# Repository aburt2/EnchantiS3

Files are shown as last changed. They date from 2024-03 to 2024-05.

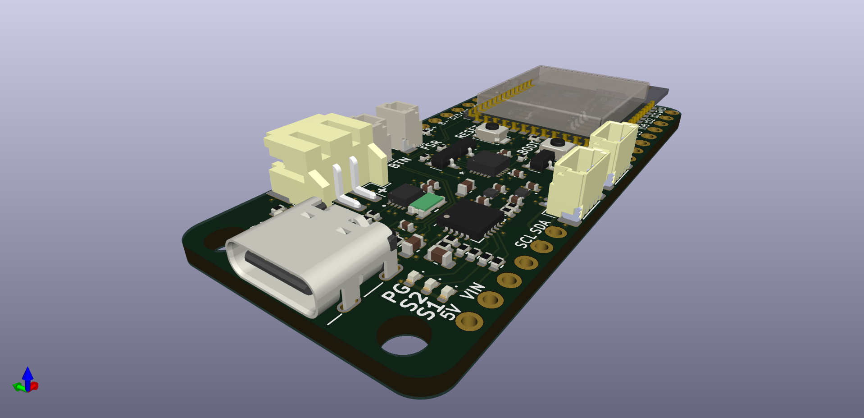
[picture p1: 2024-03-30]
enchantiS3-board/Screenshots/tstick-5gw-pro-USB-V2-pcb-angle.png

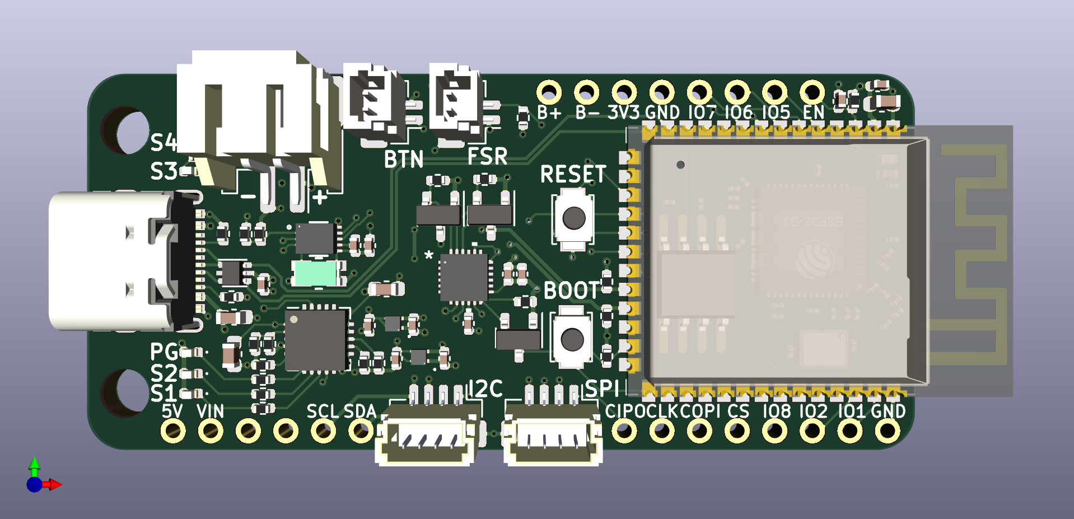
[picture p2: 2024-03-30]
enchantiS3-board/Screenshots/tstick-5gw-pro-USB-V2-pcb-front.png

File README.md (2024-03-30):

# EnchantiS3
 Repository for hardware and firmware for the EnchantiS3 board. The EnchantiS3 is a board based on the ESP32-S3 WROOM 2 module from Espressif. It includes a fuel gauge and inertial measurement unit (IMU). The board can be powered from both the USB-C port or a 3.7V lithium ion battery.

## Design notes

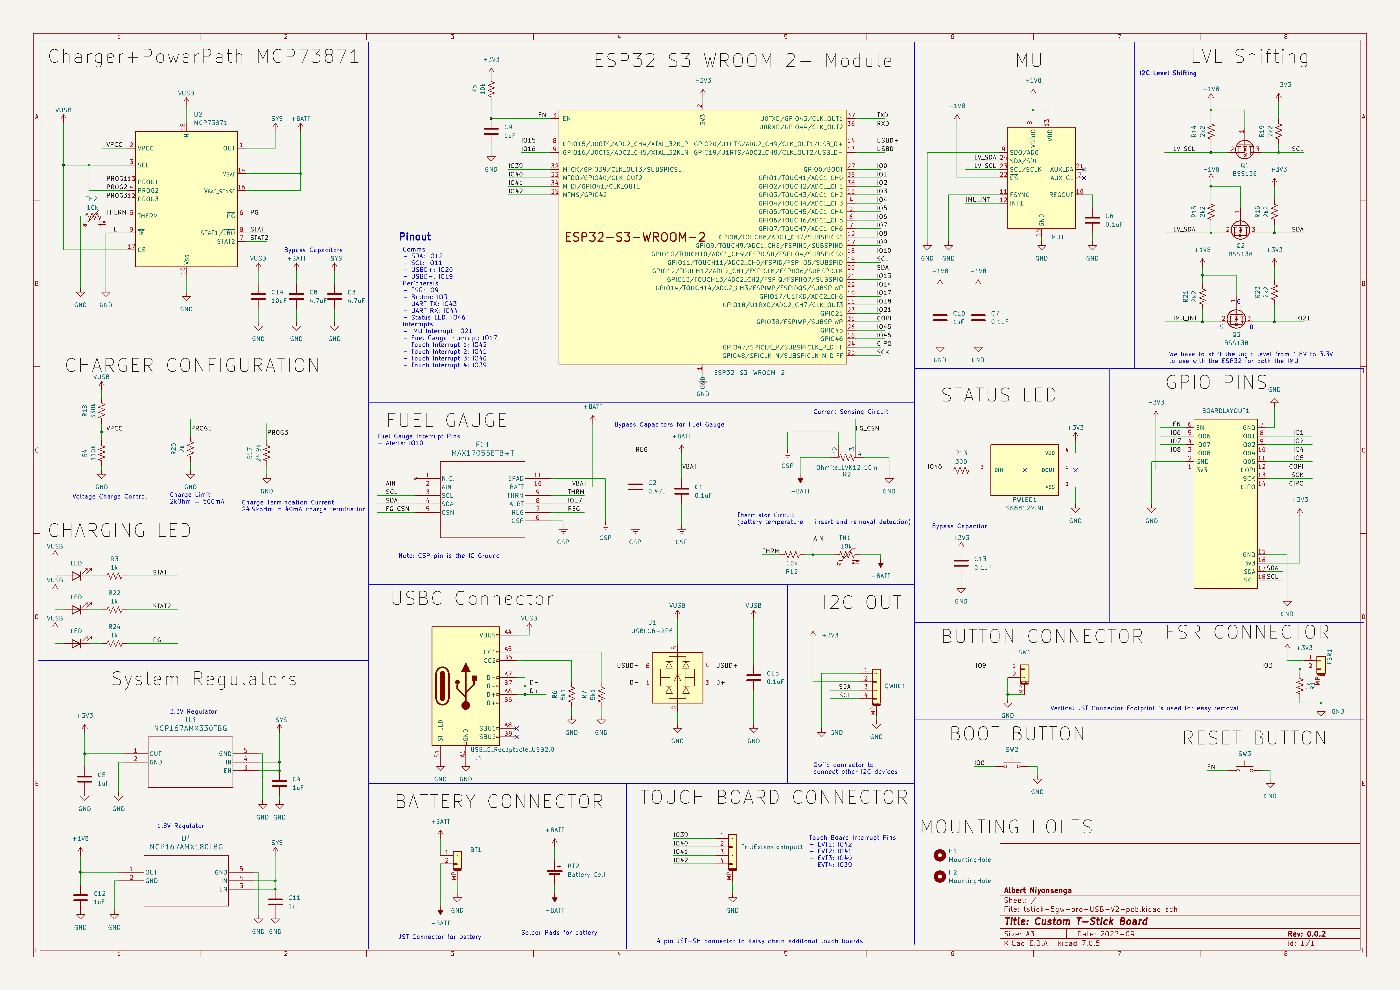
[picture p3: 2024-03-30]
enchantiS3-board/Screenshots/tstick-5GW-schematic.png

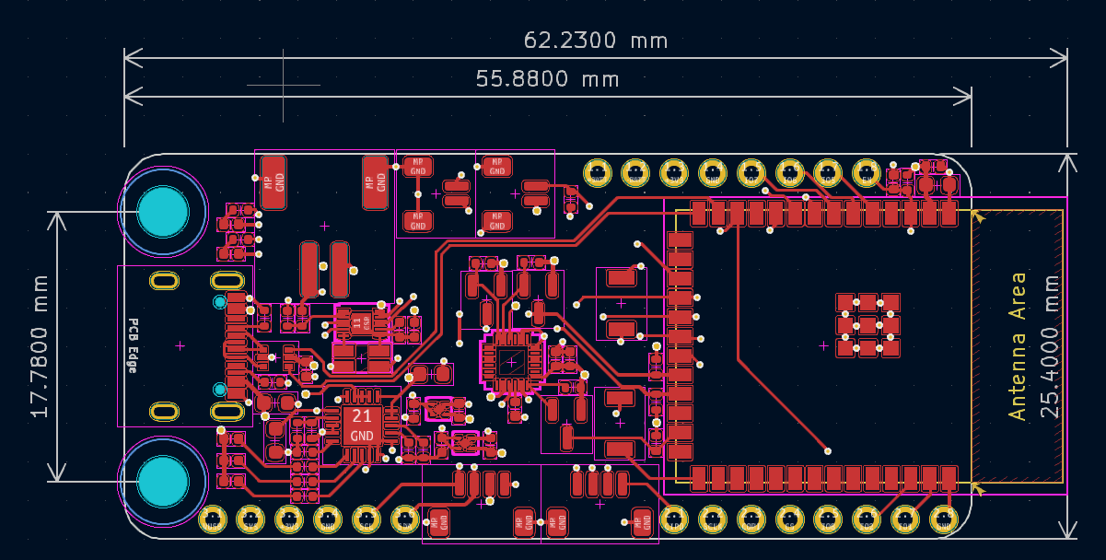
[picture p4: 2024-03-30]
enchantiS3-board/Screenshots/pcb_layout_top_layer.png

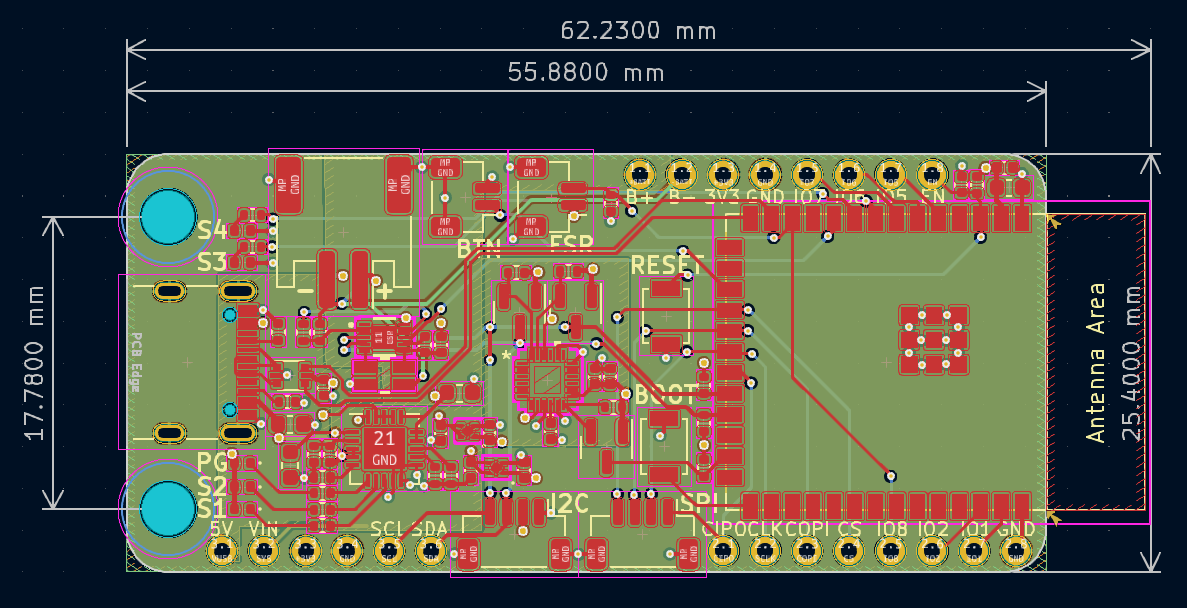
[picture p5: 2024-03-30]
enchantiS3-board/Screenshots/pcb_layout.png

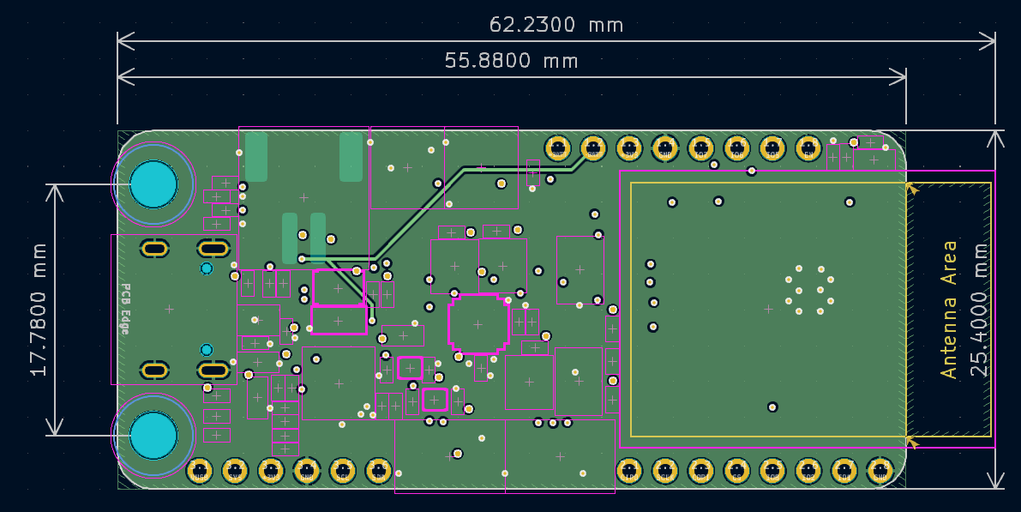
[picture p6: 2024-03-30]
enchantiS3-board/Screenshots/pcb_layout_gnd_layer.png

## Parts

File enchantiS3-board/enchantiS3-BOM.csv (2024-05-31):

Manufacturer | Mfg Part # | Qty | Reference(s) | Description Value Pkg | Note
Analog Devices Inc./Maxim Integrated | MAX17262REWL+T | 1 | U6 | Battery Fuel Gauge IC LiFePO4/Li-ion 9-WLP (1.47x1.45)
ANBON SEMICONDUCTOR (INT'L) LIMITED | BSS138 | 3 | Q1, Q2, Q3 | N-Channel 50 V 220mA (Ta) 350mW (Ta) Surface Mount SOT-23
Espressif Systems | ESP32-S3-WROOM-2-N32R8V | 1 | MCU1 | Bluetooth, WiFi 802.11b/g/n, Bluetooth v5.0 Transceiver Module 2.4GHz PCB Trace Surface Mount | Alternatives: ESP32-S3-WROOM-2-N16R8V
GCT | USB4105-GF-A | 1 | J1 | USB-C (USB TYPE-C) USB 2.0 Receptacle Connector 24 (16+8 Dummy) Position Surface Mount, Right Angle; Through Hole
Inolux | IN-S42BT5B | 1 | STATLED1 | Blue 467nm LED Indication - Discrete 2.9V 0402 (1005 Metric)
Inolux | IN-S42BT5A | 1 | STATLED2 | Amber 605nm LED Indication - Discrete 2V 0402 (1005 Metric)
JST Sales America Inc. | BM02B-SRSS-TB | 2 | ANG1, ANG2 | Connector Header Surface Mount 2 position 0.039" (1.00mm)
JST Sales America Inc. | S2B-PH-SM4-TB | 1 | BT1 | Connector Header Surface Mount, Right Angle 2 position 0.079" (2.00mm)
JST Sales America Inc. | BM04B-SRSS-TB | 2 | TOUCH1, TOUCH2 | Connector Header Surface Mount 4 position 0.039" (1.00mm)
Kingbright | APHHS1005SURCK | 1 | CHARGLED1 | Red 630nm LED Indication - Discrete 1.95V 0402 (1005 Metric)
Kingbright | APHHS1005SYCK | 1 | CHARGLED2 | Yellow 590nm LED Indication - Discrete 2V 0402 (1005 Metric)
Kingbright | APHHS1005CGCK | 1 | CHARGLED3 | Green 570nm LED Indication - Discrete 2.1V 0402 (1005 Metric)
Microchip Technology | MCP73871-2CCI/ML | 1 | U2 | QFN-20 Battery Management ICs ROHS
Murata Electronics | GRT155R61C474KE01D | 1 | C2 | 0.47 µF ±10% 16V Ceramic Capacitor X5R 0402 (1005 Metric)
Omron Electronics Inc-EMC Div | B3U-1000P | 2 | SW1, SW2 | Tactile Switch SPST-NO Top Actuated Surface Mount
onsemi | NCP167AMX330TBG | 2 | U3, U5 | Linear Voltage Regulator IC Positive Fixed 1 Output 700mA 4-XDFN (1x1), 3.3V
onsemi | NCP167AMX180TBG | 1 | U4 | Linear Voltage Regulator IC Positive Fixed 1 Output 700mA 4-XDFN (1x1), 1.8V
Panasonic Electronic Components | ERJ-2RKF1001X | 6 | R1, R3, R8, R10, R22, R24 | 1 kOhms ±1% 0.1W, 1/10W Chip Resistor 0402 (1005 Metric) Automotive AEC-Q200 Thick Film
Panasonic Electronic Components | ERJ-2RKF1103X | 1 | R4 | 110 kOhms ±1% 0.1W, 1/10W Chip Resistor 0402 (1005 Metric) Automotive AEC-Q200 Thick Film
Panasonic Electronic Components | ERJ-2RKF1002X | 2 | R5, R9 | 10 kOhms ±1% 0.1W, 1/10W Chip Resistor 0402 (1005 Metric) Automotive AEC-Q200 Thick Film
Panasonic Electronic Components | ERJ-2RKF5101X | 2 | R6, R7 | 5.1 kOhms ±1% 0.1W, 1/10W Chip Resistor 0402 (1005 Metric) Automotive AEC-Q200 Thick Film
Panasonic Electronic Components | ERJ-2RKF2201X | 6 | R14, R15, R16, R19, R21, R23 | 2.2 kOhms ±1% 0.1W, 1/10W Chip Resistor 0402 (1005 Metric) Automotive AEC-Q200 Thick Film
Panasonic Electronic Components | ERJ-2RKF2492X | 1 | R17 | 24.9 kOhms ±1% 0.1W, 1/10W Chip Resistor 0402 (1005 Metric) Automotive AEC-Q200 Thick Film
Panasonic Electronic Components | ERJ-2RKF3303X | 1 | R18 | 330 kOhms ±1% 0.1W, 1/10W Chip Resistor 0402 (1005 Metric) Automotive AEC-Q200 Thick Film
Panasonic Electronic Components | ERJ-2RKF2001X | 1 | R20 | 2 kOhms ±1% 0.1W, 1/10W Chip Resistor 0402 (1005 Metric) Automotive AEC-Q200 Thick Film
Panasonic Electronic Components | ERT-J0EG103FA | 1 | TH1 | NTC Thermistor 10k 0402 (1005 Metric)
Samsung Electro-Mechanics | CL05B104KO5NNNC | 5 | C1, C6, C7, C15, C19 | 0.1 µF ±10% 16V Ceramic Capacitor X7R 0402 (1005 Metric)
Samsung Electro-Mechanics | CL10A475KO8NNNC | 2 | C3, C8 | 4.7 µF ±10% 16V Ceramic Capacitor X5R 0603 (1608 Metric)
Samsung Electro-Mechanics | CL05A105KO5NNNC | 8 | C4, C5, C9, C10, C11, C12, C16, C17 | 1 µF ±10% 16V Ceramic Capacitor X5R 0402 (1005 Metric)
Samsung Electro-Mechanics | CL10A105KO8NNNC | 2 | C13, C14 | 10 µF ±10% 6.3V Ceramic Capacitor X5R 0603 (1608 Metric)
STMicroelectronics | USBLC6-2P6 | 1 | U1 | 17V Clamp 5A (8/20µs) Ipp Tvs Diode Surface Mount SOT-666
TDK InvenSense | ICM-20948 | 1 | IMU1 | Accelerometer, Gyroscope, Magnetometer, 9 Axis Sensor I²C, SPI Output

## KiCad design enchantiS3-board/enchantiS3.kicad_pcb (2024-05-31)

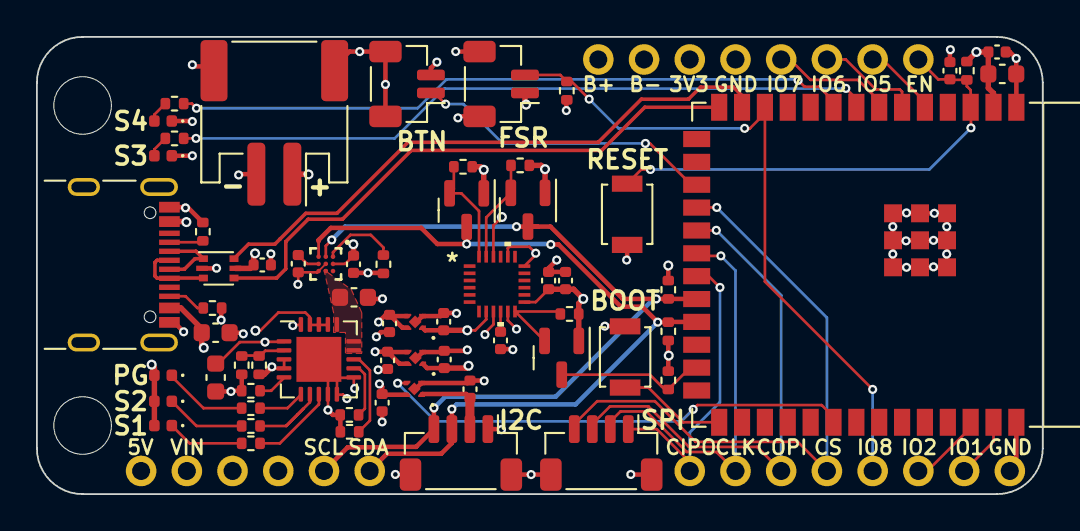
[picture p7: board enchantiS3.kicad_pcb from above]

Board: 4 copper layers, 55.9 x 25.4 mm, 66 parts (0 on the bottom side), 51 nets.

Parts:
ANG1, ANG2: JST-SH-1.00mm 1x2; JST_SH_BM02B-SRSS-TB_1x02-1MP_P1.00mm_Vertical
BOARDLAYOUT1: LAYOUT; board-layout
BT1: JST-PH-1x02-2.000mm; JST_PH_S2B-PH-SM4-TB_1x02-1MP_P2.00mm_Horizontal
C1, C6, C7, C15, C19: 0.1uF; C_0402_1005Metric
C2: 0.47uF; C_0402_1005Metric
C3, C8: 4.7uF; C_0603_1608Metric
C4, C5, C9, C10, C11, C12, C16, C17: 1uF; C_0402_1005Metric
C13, C14: 10uF; C_0603_1608Metric
CHARGLED1: S1; LED_0402_1005Metric
CHARGLED2: S2; LED_0402_1005Metric
CHARGLED3: PG; LED_0402_1005Metric
H1, H2: MountingHole; MountingHole_3.2mm_M3_DIN965
IMU1: ICM-20948; QFN24_3X3X0P9_IVS
J1: USB_C_Receptacle_USB2.0; USB_C_Receptacle_GCT_USB4105-xx-A_16P_TopMnt_Horizontal
MCU1: ESP32-S3-WROOM-2
Q1, Q2, Q3: BSS138; SOT-23
R1, R3, R8, R10, R22, R24: 1k; R_0402_1005Metric
R4: 110k; R_0402_1005Metric
R5, R9: 10k; R_0402_1005Metric
R6, R7: 5k1; R_0402_1005Metric
R14, R15, R16, R19, R21, R23: 2k2; R_0402_1005Metric
R17: 24.9k; R_0402_1005Metric
R18: 330k; R_0402_1005Metric
R20: 2k; R_0402_1005Metric
STATLED1: WIFISTATUS; LED_0402_1005Metric
STATLED2: GENERAL STATUS; LED_0402_1005Metric
SW1, SW2: B3U-1000P; SW_SPST_B3U-1000P
TH1: 10k; R_0402_1005Metric
TOUCH1, TOUCH2: JST-SH-1x04 1.0mm; JST_SH_BM04B-SRSS-TB_1x04-1MP_P1.00mm_Vertical
U1: USBLC6-2P6; SOT-666
U2: MCP73871; QFN-20-1EP_4x4mm_P0.5mm_EP2.5x2.5mm
U3, U5: NCP167AMX330TBG; XDFN4_1X1_711AJ_ONS
U4: NCP167AMX180TBG; XDFN4_1X1_711AJ_ONS
U6: MAX17262REWL+T; 21-100221A_W91G1&plus_3_MXM

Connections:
3V3_AUX: C16.1, TOUCH1.2, U5.1 (OUT)
+1V8: C7.1, C10.1, C12.1, IMU1.8 (VDDIO), IMU1.13 (VDD), IMU1.22 (~CS), Q1.1 (G), Q2.1 (G), Q3.1 (G), R14.2, R15.2, R21.2, U4.1 (OUT)
+3V3: ANG1.1, BOARDLAYOUT1.1.3 (3v3), BOARDLAYOUT1.3.3 (3v3), C5.1, C13.1, C19.1, MCU1.2 (3V3), R5.2, R16.2, R19.2, R23.2, U3.1 (OUT)
+BATT: BOARDLAYOUT1.1.1 (VBAT), BT1.1, C1.1, U6.A2 (BATT)
/CIPO: BOARDLAYOUT1.2.1 (CS), MCU1.21 (GPIO13/TOUCH13/ADC2_CH2/FSPIQ/FSPIIO7/S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), TOUCH2.1
/COPI: BOARDLAYOUT1.2.3 (SCLK), MCU1.19 (GPIO11/TOUCH11/ADC2_CH0/FSPID/FSPIIO5/S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), TOUCH2.3
/CS: BOARDLAYOUT1.2.4 (COPI), MCU1.18 (GPIO10/TOUCH10/ADC1_CH9/FSPICS0/FSPIIO4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), TOUCH2.4
/D+: J1.A6 (D+), J1.B6 (D+), U1.3 (I/O2)
/D-: J1.A7 (D-), J1.B7 (D-), U1.1 (I/O1)
/EN: BOARDLAYOUT1.1.8 (EN), C9.1, MCU1.3 (EN), R5.1, SW2.1
/IMU_INT: IMU1.12 (INT1), Q3.2 (S), R21.1
/IO0: MCU1.27 (GPIO0/BOOT), SW1.1
/IO1: BOARDLAYOUT1.2.7 (A3), MCU1.39 (GPIO1/TOUCH1/ADC1_CH0)
/IO2: BOARDLAYOUT1.2.6 (A2), MCU1.38 (GPIO2/TOUCH2/ADC1_CH1)
/IO5: BOARDLAYOUT1.1.7 (A6), MCU1.5 (GPIO5/TOUCH5/ADC1_CH4)
/IO6: BOARDLAYOUT1.1.6 (A5), MCU1.6 (GPIO6/TOUCH6/ADC1_CH5)
/IO7: BOARDLAYOUT1.1.5 (A4), MCU1.7 (GPIO7/TOUCH7/ADC1_CH6)
/IO8: ANG1.2, BOARDLAYOUT1.2.5 (A1), MCU1.12 (GPIO8/TOUCH8/ADC1_CH7/SUBSPICS1), R1.1
/IO9: ANG2.1, MCU1.17 (GPIO9/TOUCH9/ADC1_CH8/FSPIHD/SUBSPIHD)
/IO15: MCU1.8 (GPIO15/U0RTS/ADC2_CH4/XTAL_32K_P), R8.1
/IO16: MCU1.9 (GPIO16/U0CTS/ADC2_CH5/XTAL_32K_N), R10.1
/IO39: MCU1.32 (MTCK/GPIO39/CLK_OUT3/SUBSPICS1), U5.3 (EN)
/IO48: MCU1.25 (GPIO48/SPICLK_N/SUBSPICLK_N_DIFF), Q3.3 (D), R23.1
/LV_SCL: IMU1.23 (SCL/SCLK), Q1.2 (S), R14.1
/LV_SDA: IMU1.24 (SDA/SDI), Q2.2 (S), R15.1
/PG: R24.2, U2.6 (~PG)
/PROG1: R20.2, U2.13 (PROG1)
/PROG3: R17.2, U2.12 (PROG3)
/REG: C2.1, U6.C2 (REG)
/SCL: BOARDLAYOUT1.3.5 (SCL), MCU1.22 (GPIO14/TOUCH14/ADC2_CH3/FSPIWP/FSPIDQS/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), Q1.3 (D), R19.1, TOUCH1.4, U6.B1 (SCL)
/SCLK: BOARDLAYOUT1.2.2 (CIPO), MCU1.20 (GPIO12/TOUCH12/ADC2_CH1/FSPICLK/FSPIIO6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), TOUCH2.2
/SDA: BOARDLAYOUT1.3.6 (SDA), MCU1.23 (GPIO21), Q2.3 (D), R16.1, TOUCH1.3, U6.C1 (SDA)
/STAT: R3.2, U2.8 (STAT1/~LBO)
/STAT2: R22.2, U2.7 (STAT2)
/THERM: R9.2, U2.5 (THERM)
/THRM: TH1.1, U6.A1 (TH)
/USBD+: MCU1.14 (GPIO20/U1CTS/ADC2_CH9/CLK_OUT1/USB_D+), U1.4 (I/O2)
/USBD-: MCU1.13 (GPIO19/U1RTS/ADC2_CH8/CLK_OUT2/USB_D-), U1.6 (I/O1)
/VPCC: R4.2, R18.1, U2.2 (VPCC)
CHRG+: C8.1, U2.14 (V_{BAT}), U2.15 (V_{BAT}), U2.16 (V_{BAT_SENSE}), U6.B3 (SYS)
GND: ANG1.MP (MountPin), ANG2.2, ANG2.MP (MountPin), BOARDLAYOUT1.1.2 (BATGND), BOARDLAYOUT1.1.4 (GND), BOARDLAYOUT1.2.8 (GND), BOARDLAYOUT1.3.4 (GND), BT1.2, BT1.MP (MountPin), C1.2, C2.2, C3.2, C4.2, C5.2, C6.2, C7.2, C8.2, C9.2, C10.2, C11.2, C12.2, C13.2, C14.2, C15.2, C16.2, C17.2, C19.2, IMU1.9 (SDO/AD0), IMU1.11 (FSYNC), IMU1.18 (GND), IMU1.20 (GND), J1.A1 (GND), J1.A12 (GND), J1.B1 (GND), J1.B12 (GND), J1.S1 (SHIELD), MCU1.1 (GND), MCU1.40 (GND), MCU1.41 (GND), R1.2, R4.1, R6.1, R7.1, R9.1, R17.1, R20.1, STATLED1.1 (K), STATLED2.1 (K), SW1.2, SW2.2, TH1.2, TOUCH1.1, TOUCH1.MP (MountPin), TOUCH2.MP (MountPin), U1.2 (GND), U2.9 (~TE), U2.10 (V_{SS}), U2.11 (V_{SS}), U2.21 (V_{SS}), U3.2 (GND), U3.5 (GND), U4.2 (GND), U4.5 (GND), U5.2 (GND), U5.5 (GND), U6.B2 (ALRT), U6.C3 (GND)
unnamed: CHARGLED1.1 (K), R3.1
unnamed: CHARGLED2.1 (K), R22.1
unnamed: CHARGLED3.1 (K), R24.1
unnamed: C6.1, IMU1.10 (REGOUT)
unnamed: J1.A5 (CC1), R7.2
unnamed: J1.B5 (CC2), R6.2
unnamed: R8.2, STATLED1.2 (A)
unnamed: R10.2, STATLED2.2 (A)
SYS: BOARDLAYOUT1.3.2 (SYS), C3.1, C4.1, C11.1, C17.1, U2.1 (OUT), U2.20 (OUT), U3.3 (EN), U3.4 (IN), U4.3 (EN), U4.4 (IN), U5.4 (IN)
VUSB: BOARDLAYOUT1.3.1 (5v), C14.1, C15.1, CHARGLED1.2 (A), CHARGLED2.2 (A), CHARGLED3.2 (A), J1.A4 (VBUS), J1.A9 (VBUS), J1.B4 (VBUS), J1.B9 (VBUS), R18.2, U1.5 (VBUS), U2.3 (SEL), U2.4 (PROG2), U2.17 (CE), U2.18 (IN), U2.19 (IN)

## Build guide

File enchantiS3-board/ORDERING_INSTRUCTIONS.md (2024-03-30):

# How to order board from PCBWAY

This file contains instructions for ordering the a PCB from PCBWAY for both fabrication and assembly. If you have the PCBWAY plugin from Kicad you can press use the plugin and skip straight to step 10

## Ordering from PCBWAY
1. Click the **PCB Instant Quote** button in the taskbar at the top of the screen.
2. Click the green **Quick-order PCB>>** button.
3. Press the grey **+Add Gerber File** button.
4. Select the **.kicad_pcb.zip** file. Several paramaeters should now autofill.
    - For a 4 layer board it may ask you to specify the layer names and order you should fill in the following:
        - L1 = F.Cu
        - L2 = In1.Cu
        - L3 = In2.Cu
        - L4 = B.Cu
5. Select the appropiate quantity.
6. Scroll further down to the **Assembly Service** section and click it.
7. Write the appropriate quantity of boards you wish to be assembled.
8. Click the green **Save to Cart** button.
9. You will now see two orders one for the fabrication and the other for assembly. Click the blue **Add files button for assembly**.
10. Click the **Parts List (BOM) Upload** and add the **BOM.csv** file for the board. 
    - Note that if you used the Kicad plugin you will need to remove the BOM file that has been uploaded as it does not have all the information needed.
11. _(Optional)_ Click the **Upload Centroid File** button and add the **PCBWay_positions.csv** file. This file is already in the **.kicad_pcb.zip** file but the customer support may require you to submit it seperately.
12. Make sure to check your inbox 24-72 hours after the purchase for PCBWAY to review the file and give the final quote.
13. Once the paid the order will go into production.

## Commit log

2024-03-30 add the enchantiS3 revision 2 board files
    [PCBWay_positions.csv, enchantiS3-BOM.csv, enchantiS3.kicad_pcb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]
2024-03-30 added revision 3 board design
    [PCBWay_positions.csv, enchantiS3-BOM.csv, enchantiS3.kicad_pcb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]
2024-05-23 added IDMIL and McGill logos
    [enchantiS3.kicad_pcb]
2024-06-21 fix BOM for revision 3 of the board
    [enchantiS3.kicad_sch]
